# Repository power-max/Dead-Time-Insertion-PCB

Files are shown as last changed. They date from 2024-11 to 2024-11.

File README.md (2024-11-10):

# Dead Time Insertion PCB

This KiCad PCB module is designed to take a single-ended TTL level square wave signal from some source and create a sort of "complementary output" but with the propagation delay for the rising edge signal delayed significantly more than the falling edge (or the opposite case if the output is inverted). This allows for driving the high and low side of a half bridge to ensure break-before-make condition.

The pinout of the 0.1 pin header has several options.

## Pin 1 (DEADTIME_CTRL)
This pin allows a current source to control the amount of deadtime that this circuit implements. It simply feeds a current mirror. A lower current will allow for a slower discharge of C5 and C6, which concequentally lead to increased the deadtime. The unfortunate side-effect is this also increases the propagation delay for signals propagating throught this block, particularly for changing the state of switching ON the switching element. Perhaps there is a way to beat causality? please let me know!

## Pin 2 (INPUT)
This is the single TTL level square wave input that is to be converted to a complimentary output for the half bridge.

## Pin 3 (INVERT)
Invert output allows the output pins 7 and 8 to be inverted, such as may be required if you are using an inverted input gate driver IC. Set this HIGH if you wish to use inverting FET driver IC.

## Pin 4 (~EN) 
This is just an ENABLE. The outputs are held at whatever the respective LOW state would be depending on the state of Pin 3, ensuring both Hi and Lo side FETs remain OFF.

## Pin 5 (VCC)
power for the circuit. Added an LDO regulator footprint (SOT-89) to the circuit, would recommend an LDO to allow operation down to around 3V depending on output voltage requirements and input voltage range.

## Pin 6 (GND)
GND, RTN, or COM. Whatever you prefer to call it.

## Pin 7 (OUT_L)
This is the output intended for the LO-side switching element gate driver.

## Pin 8 (OUT_H)
This is the output intended for the HI-side switching element gate driver.

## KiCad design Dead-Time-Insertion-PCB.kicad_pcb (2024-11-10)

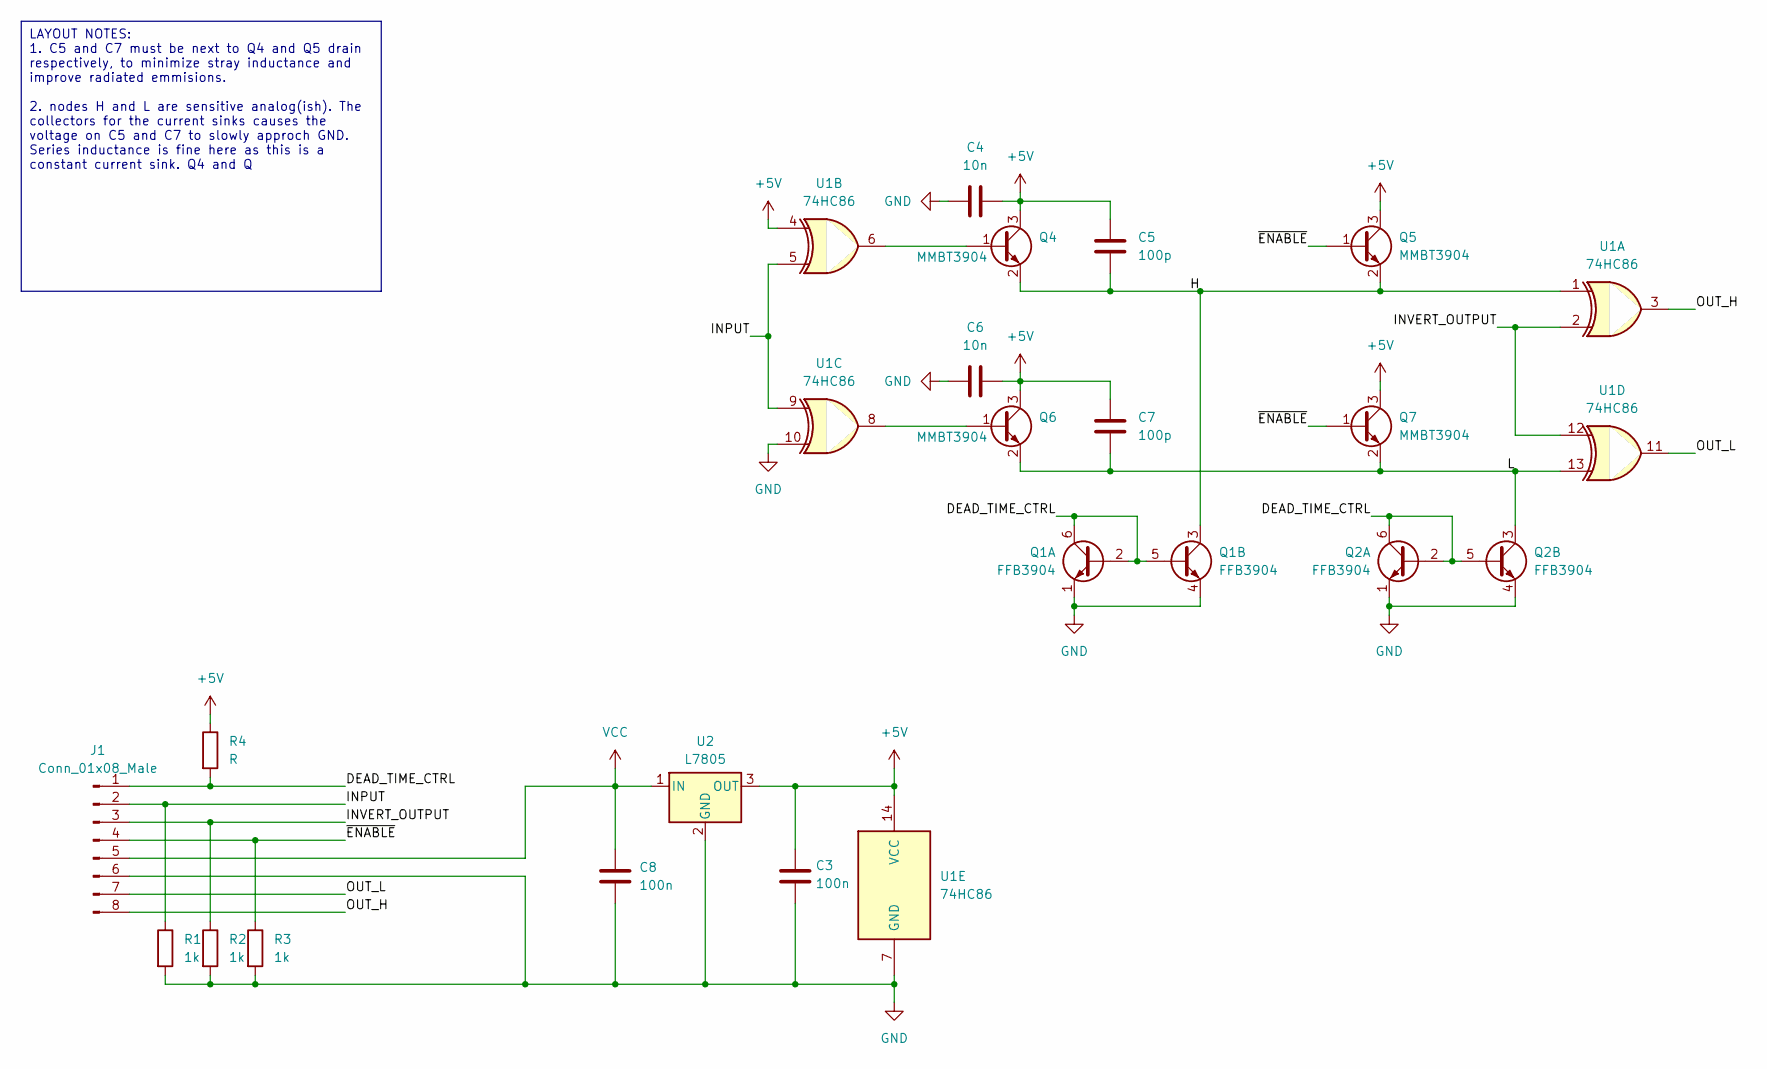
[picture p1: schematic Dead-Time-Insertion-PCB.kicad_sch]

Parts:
C3, C8: 100n; C_0603_1608Metric
C4, C6: 10n; C_0603_1608Metric
C5, C7: 100p; C_0603_1608Metric
J1: Conn_01x08_Male; PinHeader_1x08_P2.54mm_Vertical
Q1, Q2: FFB3904; SOT-363_SC-70-6
Q4, Q5, Q6, Q7: MMBT3904; SOT-23
R1, R2, R3: 1k; R_0603_1608Metric
R4: R; R_0603_1608Metric
U1: 74HC86; SOIC-14_3.9x8.7mm_P1.27mm
U2: L7805; SOT-89-3

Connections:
+5V: C3.1, C4.1, C5.1, C6.1, C7.1, Q4.3 (C), Q5.3 (C), Q6.3 (C), Q7.3 (C), R4.1, U1.4, U1.14 (VCC), U2.3 (OUT)
/DEAD_TIME_CTRL: J1.1, Q1.2 (B1), Q1.5 (B2), Q1.6 (C1), Q2.2 (B1), Q2.5 (B2), Q2.6 (C1), R4.2
/H: C5.2, Q1.3 (C2), Q4.2 (E), Q5.2 (E), U1.1
/INPUT: J1.2, R1.1, U1.5, U1.9
/INVERT_OUTPUT: J1.3, R2.1, U1.2, U1.12
/L: C7.2, Q2.3 (C2), Q6.2 (E), Q7.2 (E), U1.13
/OUT_H: J1.8, U1.3
/OUT_L: J1.7, U1.11
/~ENABLE: J1.4, Q5.1 (B), Q7.1 (B), R3.1
GND: C3.2, C4.2, C6.2, C8.2, J1.6, Q1.1 (E1), Q1.4 (E2), Q2.1 (E1), Q2.4 (E2), R1.2, R2.2, R3.2, U1.7 (GND), U1.10, U2.2 (GND)
unnamed: Q4.1 (B), U1.6
unnamed: Q6.1 (B), U1.8
VCC: C8.1, J1.5, U2.1 (IN)

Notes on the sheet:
LAYOUT NOTES: 1. C5 and C7 must be next to Q4 and Q5 drain respectively, to minimize stray inductance and improve radiated emmisions. 2. nodes H and L are sensitive analog(ish). The collectors for the current sinks causes the voltage on C5 and C7 to slowly approch GND. Series inductance is fine her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

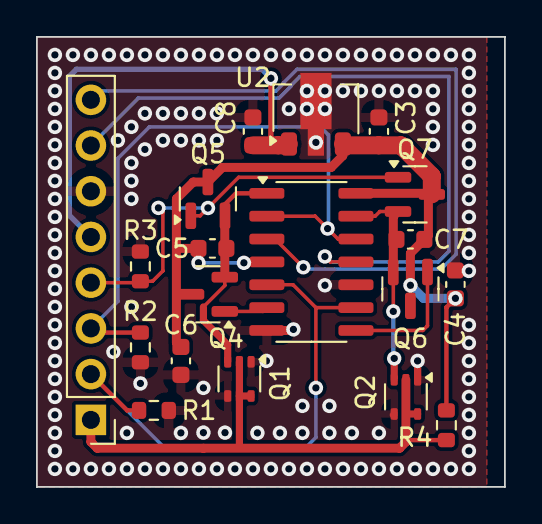
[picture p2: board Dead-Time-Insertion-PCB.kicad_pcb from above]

Board: 2 copper layers, 26.0 x 25.0 mm, 19 parts (0 on the bottom side), 13 nets.

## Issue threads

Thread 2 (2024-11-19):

Generate LUT for deadtime control current to deadtime (μs)

power-max, 2024-11-19:
The pullup resistor or current sunk into the deadtime pin defines the charging rate of the capacitors which coupled with the threshold voltages of the 7400 series chosen, will result in a certain seedtime.

Map out the current nessesary to implement different amounts dead time for various 74HC series and 74LVC. Actually not 100% sure 74LVC family will even work given the low voltage of 1V8 to 3V3 and the saturation voltage of the current BJTs at 666mV.

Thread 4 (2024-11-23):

LDO pinout is wrong

power-max, 2024-11-23:
Swap Vin Vout

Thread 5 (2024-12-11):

INVERT pin inverted

power-max, 2024-12-11:
invert the inverted control pin so it is inverted compared to the currently inverted state it is in now.

Default should be pulldown not inverted, not inverted. Or update the silkscreen to ~INVERTED to indicate the inverted by defualt state. or change to pullup Idfk.

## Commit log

2022-08-12 Added PCB Files
    [Dead-Time-Insertion-PCB-B_Cu.gbr, Dead-Time-Insertion-PCB-B_Mask.gbr, Dead-Time-Insertion-PCB-B_Paste.gbr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]
2024-11-10 added voltage regulator so I don't blow this board up with 12V
    [Dead-Time-Insertion-PCB-B_Cu.gbr, Dead-Time-Insertion-PCB-B_Mask.gbr, Dead-Time-Insertion-PCB-B_Paste.gbr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]
2024-11-10 Update README.md
    updated Pin 5 description to reflect update to PCB
2024-11-10 Update .gitignore
    Added rule for ignoring zip files since often the /gerbers file (containing the gerbers and drill file) is compressed for upload to a PCB manufacturing house.
2024-11-10 Delete gerbers.zip
    zip file is entirely redundant with the /gerbers folder.
2024-11-10 addressed parasitic oscillations by adding pulldown/pullup resistors, overhauling the PCB layout to reduce the footprint of sensitive nodes, took great care to avoid cross coupling of input and outpu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
    [Dead-Time-Insertion-PCB.kicad_pcb, Dead-Time-Insertion-PCB.kicad_sch]
2024-11-10 forgot to update the gerbers
    [Dead-Time-Insertion-PCB-B_Cu.gbr, Dead-Time-Insertion-PCB-B_Mask.gbr, Dead-Time-Insertion-PCB-B_Paste.gbr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]
2024-11-10 Update .gitignore
    add ignore any file starting with ~ (KiCAD uses new temp files??)
